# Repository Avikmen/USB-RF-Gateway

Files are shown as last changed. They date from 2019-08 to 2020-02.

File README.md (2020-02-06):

## USB RF Gateway on NRF24L01 or RFM69

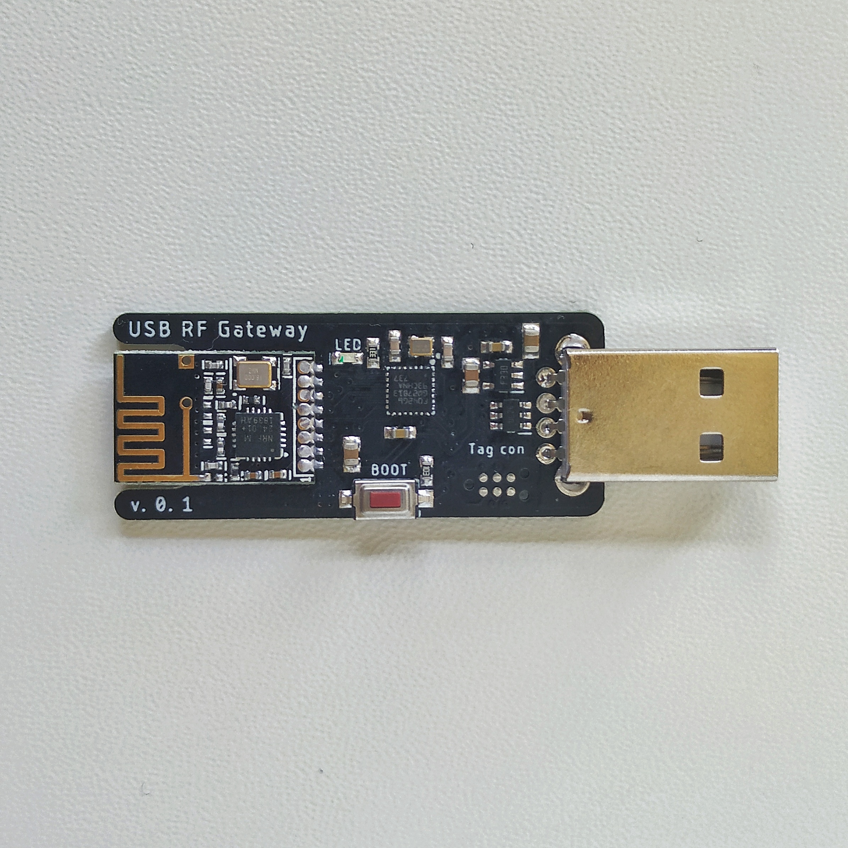
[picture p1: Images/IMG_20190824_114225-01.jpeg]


  This is my mini project on STM32. Many makers use low cost radio transmitters NRF24L01 and RFM69 in their projects. This PCB should facilitate the use of radio modules for use as transmitters in USB devices. Can also be used as a RF-dongle for Raspberry Pi. 
  The basis of the device is the microcontroller STM32F042G6U6 in the case UFQFPN28 4x4 mm (smallest footprint controller enclosure I found on sale). 
  It is possible to download .bin files directly via USB, thanks to the built-in bootloader. For the whole, you’ll need to connect device in USB port on while holding down the “BOOT” button. I used STM32CubeProgrammer to download .bin file. 6-pin SWD Tag-Connect is also available for debugging.
  
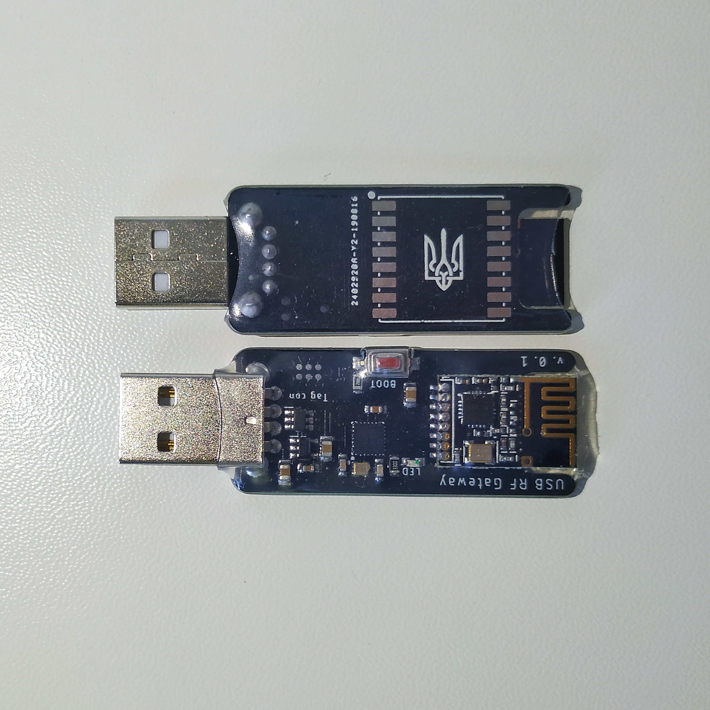
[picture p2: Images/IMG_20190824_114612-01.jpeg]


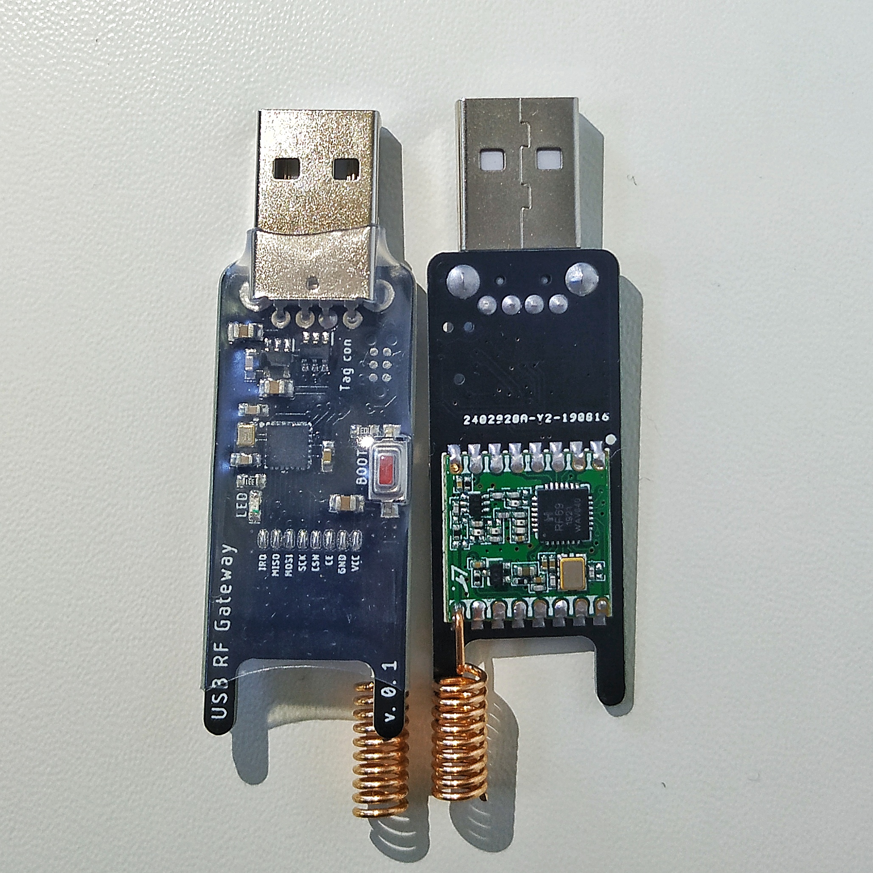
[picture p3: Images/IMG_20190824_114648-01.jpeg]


You can place the programmed and debugged device in the enclosure of Gainta G1901G or G1901C. I specifically tried to develop this device for such cases, because they are quite cheap and universal.

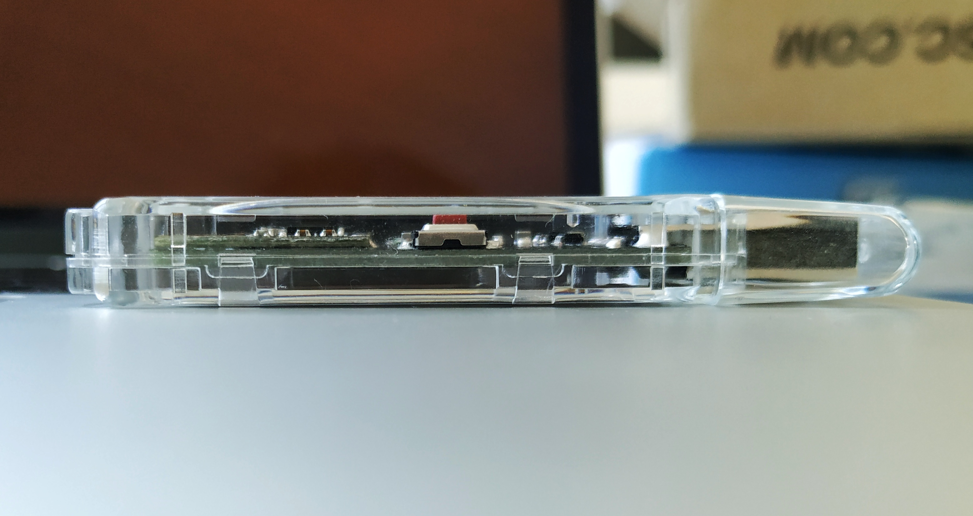
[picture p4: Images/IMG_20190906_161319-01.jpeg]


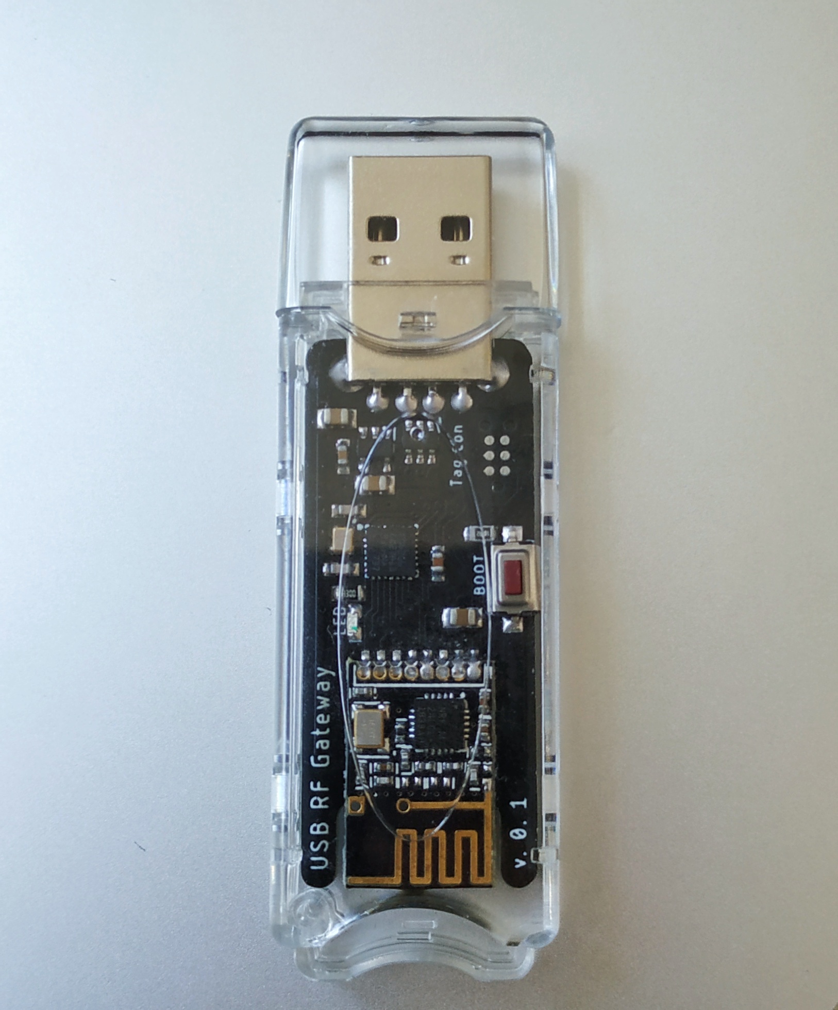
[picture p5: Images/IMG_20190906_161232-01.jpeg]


### Features

- NRF24L01 SMD
- RFM69 868 or 915 MHz (to minimize antenna size, compared to antenna sizes for 433MHz)
- No programming probe needed for uploading firmware
- Tag-Connect for debugging
- Debugging LED on board
- USB port ESD protection
- The NRF24L01 *(not tested RFM69 version)* version is perfect for the Gainta G1901C or 1901G enclosure (if you use a USB connector for deep PCB landing)
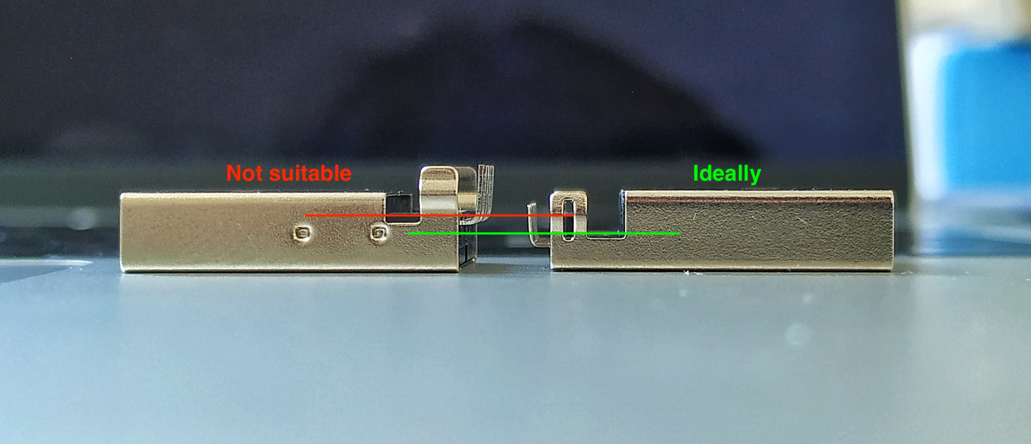
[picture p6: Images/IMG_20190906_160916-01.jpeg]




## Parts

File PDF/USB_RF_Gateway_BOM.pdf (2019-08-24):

USB RF Gateway v.0.1 BOM

Qty | Value | Device | Package | Parts | Description
1 | Blue | LED0603 | LED-0603 | D2 | LED (Generic)
1 | 100nF | C-EUC0603 | C0603 | C7 | CAPACITOR, European symbol
1 | 10K | R-EU_R0603 | R0603 | R1 | RESISTOR, European symbol
3 | 10uF | C-EUC0805 | C0805 | C3, C4, C6 | CAPACITOR, European symbol
1 | 1uF | C-EUC0603 | C0603 | C5 | CAPACITOR, European symbol
2 | 20pF | C-EUC0603 | C0603 | C1, C2 | CAPACITOR, European symbol
1 | 330 Ohm | R-EU_R0603 | R0603 | R2 | RESISTOR, European symbol
1 | 868MHz | RFM69HCW-868 | RFM69HCW-XXXS2 | U1 | Hope RF RFM69H ISM Transceiver Module
1 | ECS-160-12-37B-CTN-TR | ECS-160-12-37B-CTN-TR | ECS-160-12-37B-CTN | U$1
1 | LDS3985M33R | LDS3985M33R | SOT95P280X145-5N | IC1 | STMicroelectronics LDS3985M33R, Single Low Dropout Voltage Regulator, 300mA 3.3 V, 5-Pin SOT-23
1 | MOMENTARY-SWITCH-SPST-SMD-6.0X3.5MM | MOMENTARY-SWITCH-SPST-SMD-6.0X3.5MM | TACTILE_SWITCH_SMD_6.0X3.5MM | S1 | Momentary Switch (Pushbutton) - SPST
1 | NRF24L01+NRF24L01+MINI | NRF24L01+NRF24L01+MINI | NRF24L01+MINI | U$2 | nRF24L01+ Transceiver Module
1 | STMF042G6U6 | STMF042G6U6 | STM32F042_UFQPN28_4X4MM | U$3
1 | USBLC6-2SC6Y | USBLC6-2SC6Y | SOT95P280X145-6N | D1 | Low Cap. ESD Protection Auto SOT-23-6 STMicroelectronics USBLC6-2SC6Y, Dual Uni-Directional TVS Diode Array, 6-Pin SOT-23
1 | USB_A_PTH_MALE | USB_A_PTH_MALE | USB-A-H | J3 | USB-A Connector

1

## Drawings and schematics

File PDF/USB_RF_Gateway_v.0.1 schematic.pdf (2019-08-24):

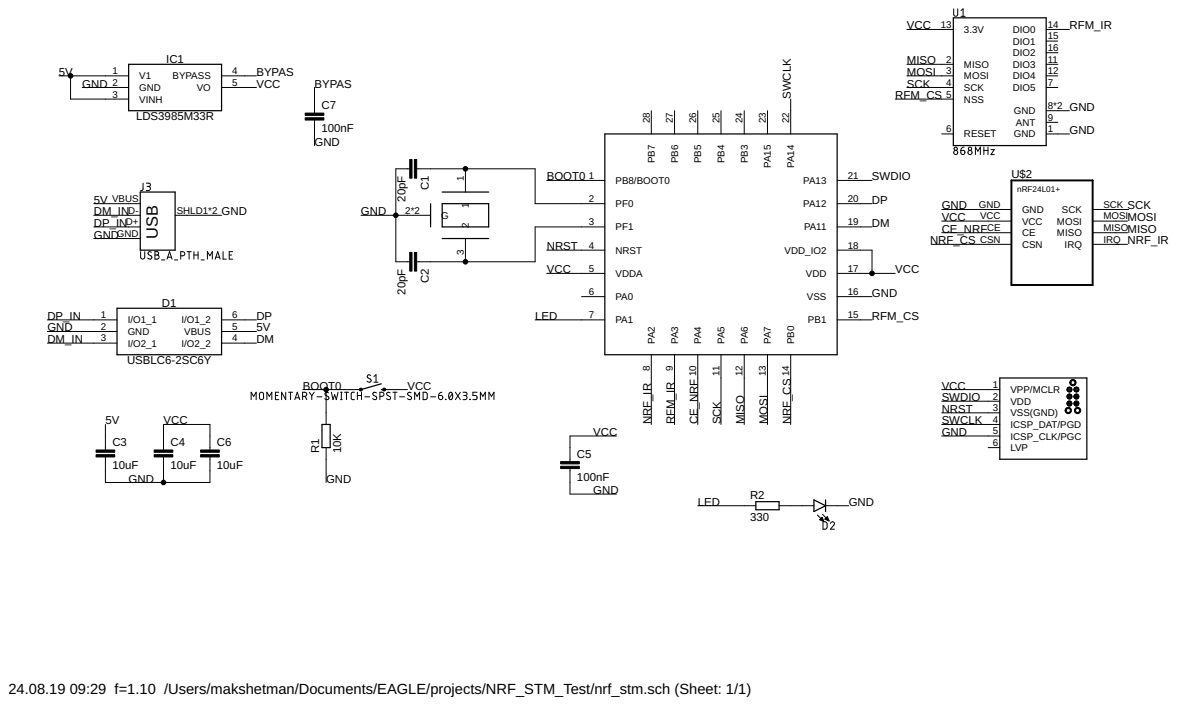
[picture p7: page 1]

24.08.19 09:29 f=1.10 /Users/makshetman/Documents/EAGLE/projects/NRF_STM_Test/nrf_stm.sch (Sheet: 1/1)

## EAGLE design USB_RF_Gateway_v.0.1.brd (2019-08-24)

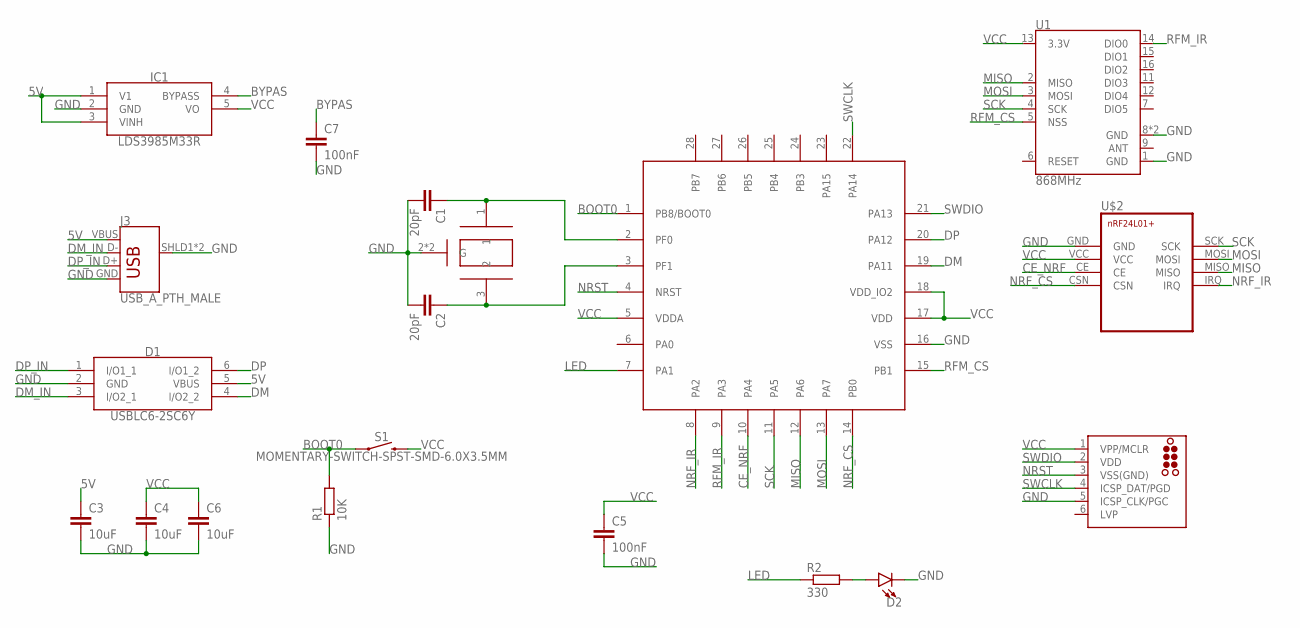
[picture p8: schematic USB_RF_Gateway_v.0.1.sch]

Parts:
C1, C2: 20pF; C0603
C3, C4, C6: 10uF; C0805
C5, C7: 100nF; C0603
D1: USBLC6-2SC6Y; SOT95P280X145-6N
D2: LED0603; LED-0603
IC1: LDS3985M33R; SOT95P280X145-5N
J2: TC2030-MCP-NL
J3: USB_A_PTH_MALE; USB-A-H
R1: 10K; R0603
R2: 330; R0603
S1: MOMENTARY-SWITCH-SPST-SMD-6.0X3.5MM; TACTILE_SWITCH_SMD_6.0X3.5MM
U1: 868MHz; RFM69HCW-XXXS2
U$1: ECS-160-12-37B-CTN-TR; ECS-160-12-37B-CTN
U$2: NRF24L01+NRF24L01+MINI; NRF24L01+MINI
U$3: STMF042G6U6; STM32F042_UFQPN28_4X4MM

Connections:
5V: C3.1, D1.5 (VBUS), IC1.1 (V1), IC1.3 (VINH), J3.VBUS
BOOT0: R1.2, S1.1, U$3.1 (PB8/BOOT0)
BYPAS: C7.1, IC1.4 (BYPASS)
CE_NRF: U$2.CE, U$3.10 (PA4)
DM: D1.4 (I/O2_2), U$3.19 (PA11)
DM_IN: D1.3 (I/O2_1), J3.D-
DP: D1.6 (I/O1_2), U$3.20 (PA12)
DP_IN: D1.1 (I/O1_1), J3.D+
GND: C1.2, C2.2, C3.2, C4.2, C5.2, C6.2, C7.2, D1.2 (GND), D2.C, IC1.2 (GND), J2.5 (ICSP_CLK/PGC), J3.GND, J3.SHLD1 (SHIELD), J3.SHLD2 (SHIELD), R1.1, U1.1 (GND), U1.8 (GND), U1.10 (GND), U$1.2 (G), U$1.4 (G), U$2.GND, U$3.16 (VSS)
LED: R2.1, U$3.7 (PA1)
MISO: U1.2 (MISO), U$2.MISO, U$3.12 (PA6)
MOSI: U1.3 (MOSI), U$2.MOSI, U$3.13 (PA7)
unnamed: C1.1, U$1.1, U$3.2 (PF0)
unnamed: C2.1, U$1.3 (2), U$3.3 (PF1)
unnamed: D2.A, R2.2
NRF_CS: U$2.CSN, U$3.14 (PB0)
NRF_IR: U$2.IRQ, U$3.8 (PA2)
NRST: J2.3 (VSS(GND)), U$3.4 (NRST)
RFM_CS: U1.5 (NSS), U$3.15 (PB1)
RFM_IR: U1.14 (DIO0), U$3.9 (PA3)
SCK: U1.4 (SCK), U$2.SCK, U$3.11 (PA5)
SWCLK: J2.4 (ICSP_DAT/PGD), U$3.22 (PA14)
SWDIO: J2.2 (VDD), U$3.21 (PA13)
VCC: C4.1, C5.1, C6.1, IC1.5 (VO), J2.1 (VPP/MCLR), S1.2, U1.13 (3.3V), U$2.VCC, U$3.5 (VDDA), U$3.17 (VDD), U$3.18 (VDD_IO2)

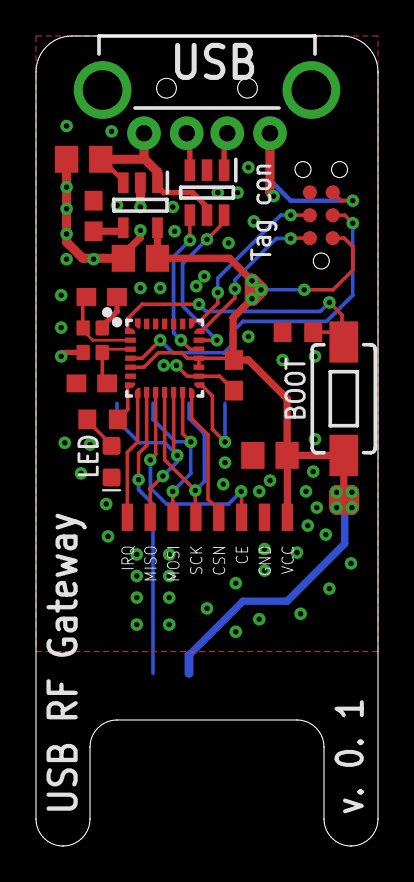
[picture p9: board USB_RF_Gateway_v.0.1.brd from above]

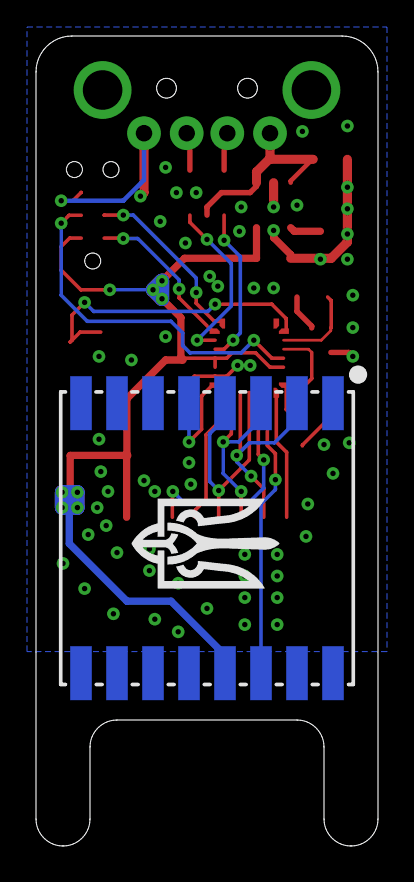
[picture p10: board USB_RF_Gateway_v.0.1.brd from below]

Board: 2 copper layers, 19.0 x 45.0 mm, 20 parts (2 on the bottom side), 24 nets.

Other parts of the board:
U$4: GERB_5MM

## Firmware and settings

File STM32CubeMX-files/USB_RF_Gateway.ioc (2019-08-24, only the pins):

Mcu.UserName=STM32F042G6Ux
PA1.GPIO_Label=LED
PA1.Signal=GPIO_Output
PA11.Signal=USB_DM
PA12.Signal=USB_DP
PA13.Signal=SYS_SWDIO
PA14.Signal=SYS_SWCLK
PA2.GPIO_Label=NRF_IR
PA2.Signal=GPXTI2
PA3.GPIO_Label=RFM_IR
PA3.Signal=GPXTI3
PA4.GPIO_Label=CE_NRF
PA4.Signal=GPIO_Output
PA5.Signal=SPI1_SCK
PA6.Signal=SPI1_MISO
PA7.Signal=SPI1_MOSI
PB0.GPIO_Label=NRF_CS
PB0.Signal=GPIO_Output
PB1.GPIO_Label=RFM_CS
PB1.Signal=GPIO_Output
PF0-OSC_IN.Signal=RCC_OSC_IN
PF1-OSC_OUT.Signal=RCC_OSC_OUT

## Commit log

2019-08-24 Add device photos
2019-09-06 Photos of the enclosure G1901C added
2020-02-06 Update README.md
    Added button to buy on Tindie store

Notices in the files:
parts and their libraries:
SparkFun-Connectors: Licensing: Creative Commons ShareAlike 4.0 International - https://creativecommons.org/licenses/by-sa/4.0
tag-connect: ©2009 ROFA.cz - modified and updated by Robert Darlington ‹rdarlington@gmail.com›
